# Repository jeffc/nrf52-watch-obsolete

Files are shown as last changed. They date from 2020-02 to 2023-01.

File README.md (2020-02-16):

# nrf52-watch

## Overview

This repo is, at present, a work-in-progress playground for designing and
building a smartwatch based on the nrf52840 microcontroller from Nordic.

## Parts

  * [RayTac MDBT50Q nRF52840 Module](https://www.raytac.com/product/ins.php?index_id=24)
    * Main brains. nRF52840 chipset chosen for BLE capability and low (&lt;1uA)
      sleep current.
    * This is the module used in the [Sparkfun Breakout](https://www.sparkfun.com/products/15025)
  * [Sharp LS018B7DH02 1.8" Memory LCD with FLExLight Frontlight](https://www.digikey.com/product-detail/en/flex-lighting/12616-06_T1/12616-06_T1-ND/9602610)
    * Always-on display.
    * Chosen for size and small power consumption.
    * The LS018B7DH02 isn't sold directly by Sharp, and no datasheet is
      currently available.
    * Unknowns are currently
      * Does the display require 3.3V or 5V power?
      * Does the display require 3.3V or 5V logic?
      * Does the display require a 1Hz or 60Hz square wave for biasing? 3.3V
        models tend to need 60Hz, but the 5V models need 1Hz
  * [M41T62Q6F RTC](https://www.digikey.com/product-detail/en/stmicroelectronics/M41T62Q6F/497-3907-1-ND/714738)
    * Realtime clock, for real timekeeping.
    * Chosen for small power consumption and footprint
    * This module can also provide the 1Hz or 64Hz square wave required by the
      memory LCD, which means fewer wakeups for the nRF52840
  * [MCP73831T Battery Charger IC](https://www.digikey.com/product-detail/en/microchip-technology/MCP73831T-2DCI-OT/MCP73831T-2DCI-OTCT-ND/1979804) 
    * Charges at 4.2V
  * USB-C port for power, charging, and data
    * I'm cheating here and using USB 2.0 Compatibility mode, so I don't get the
      benefits of USB-PD.

## Power

  * Project will be powered by a [500mAh LiPo](https://www.adafruit.com/product/1578),
    which has a nominal capacity of 500mAh at 3.7V.
    * Battery chosen has built-in overcurrent and undervoltage protection
      circuitry, meaning that I don't have to design any.
  * Projected lifetime is &gt;2mo, though it remains to be seen if this is
    possible

## Manufacture and Assembly

  * Prototypes of the case and mechanical components will be 3D printed.
  * Once I have a design that I like, I'll send the files to
    [Shapeways](http://shapeways.com) or [ExOne](http://exone.com) to be 3D
    Printed in steel.
  * Side buttons (required since the display is not a touch screen) will be on
    separate PCBs, connected via JST-SH cables to the main PCB. This allows me
    to use normal PCB buttons rather than right-angle ones, and gives some
    flexibility in mounting the main PCB.

## Software

  Since there isn't code written yet, this section is largely my notepad on
  ideas and framework setup.

  * To conserve power, everything will be interrupts-driven. 
  * PlatformIO doesn't have a builtin for the sparkfun dev board I'm using, so
    the packages/ directory and corresponding lines in platformio.ini are a
    workaround to keep the repository as portable as possible
  * A decent amount of build hackery was needed to make the native version build
    with the dummy adafruit_gfx library

## Credits / Inspiration

  * This project uses open-source code from the following projects. Licenses are
    included alongside code where applicable.
    * [Adafruit](https://github.com/adafruit/Adafruit-GFX-Library)
    * [vhervieux on github](https://github.com/croutor/Adafruit_GFX_dummy_display)
    * [jeraymond on github](https://github.com/jeraymond/pio-sparkfun_pro_nrf52840_mini-setup)
    * [UF2Conv from Microsoft](https://raw.githubusercontent.com/microsoft/uf2/master/utils/uf2conv.py)
  * This project took inspiration from these projects:
    * [Chronio](https://hackaday.io/project/12876-chronio)
    * [Samson March's Smartwatch](https://imgur.com/a/FSBwD3g)

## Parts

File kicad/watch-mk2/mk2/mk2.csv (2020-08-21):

Comment | Designator | Package | LCSC
Battery_Cell | BT1 | Connector_JST:JST_SH_BM02B-SRSS-TB_1x02-1MP_P1.00mm_Vertical
12pF | C1,C2 | Capacitor_SMD:C_0603_1608Metric_Pad1.05x0.95mm_HandSolder | C38523
0.47uF | C10 | Capacitor_SMD:C_0603_1608Metric_Pad1.05x0.95mm_HandSolder | C1623
10uF | C3,C6,C7,C8 | Capacitor_SMD:C_0603_1608Metric_Pad1.05x0.95mm_HandSolder | C19702
4.7uF | C4,C20 | Capacitor_SMD:C_0603_1608Metric_Pad1.05x0.95mm_HandSolder | C19666
11mF | C5 | Capacitor_SMD:C_1210_3225Metric_Pad1.42x2.65mm_HandSolder
560pF | C9 | Capacitor_SMD:C_0603_1608Metric_Pad1.05x0.95mm_HandSolder
D_Schottky_x2_KCom_AAK | D1 | Package_TO_SOT_SMD:TSOT-23
D_Schottky | D2 | Diode_SMD:D_0603_1608Metric_Pad1.05x0.95mm_HandSolder
MDBT50Q | IC1 | 113990582:113990582 | C155330
M41T62LC6F | IC2 | libs:LCC90P230X50X80-8N
Conn_01x10_Female | J1 | Connector_FFC-FPC:Hirose_FH12-10S-0.5SH_1x10-1MP_P0.50mm_Horizontal
USB_C_Receptacle_USB2.0 | J2 | Connector_USB:USB_C_Receptacle_Palconn_UTC16-G
Conn_01x02_Female | J3 | Connector_PinHeader_1.00mm:PinHeader_1x02_P1.00mm_Vertical
Conn_01x04_Female | J5 | libs:ffc-0.5mm-4
FUEL_BYP | JP1 | Resistor_SMD:R_0603_1608Metric
2.2uH | L1,L2 | Inductor_SMD:L_0603_1608Metric_Pad1.05x0.95mm_HandSolder
AXT610124 | P1 | libs:PANASONIC_AXT610124
Si1308EDL | Q3,Q4 | Package_TO_SOT_SMD:SOT-323_SC-70 | C469327
5.1k | R11,R12 | Resistor_SMD:R_0603_1608Metric_Pad1.05x0.95mm_HandSolder | C23186
1k | R14,R16 | Resistor_SMD:R_0603_1608Metric_Pad1.05x0.95mm_HandSolder | C21190
27 | R3,R4 | Resistor_SMD:R_0603_1608Metric_Pad1.05x0.95mm_HandSolder | C25190
100k | R5,R13,R15 | Resistor_SMD:R_0603_1608Metric_Pad1.05x0.95mm_HandSolder | C25803
10k | R6 | Resistor_SMD:R_0603_1608Metric_Pad1.05x0.95mm_HandSolder | C25804
2k | R9 | Resistor_SMD:R_0603_1608Metric_Pad1.05x0.95mm_HandSolder | C22975
B5 | SW1 | libs:E-Switch-TL3330AF130QG-MFG
B1 | SW2 | libs:E-Switch-TL3330AF130QG-MFG
B3 | SW4 | libs:E-Switch-TL3330AF130QG-MFG
SW_Push | SW_RESET1 | Button_Switch_SMD:SW_SPST_CK_KXT3
TestPoint | TP1,TP2,TP3,TP4 | TestPoint:TestPoint_Pad_D1.0mm
W25X20CLUXIG | U1 | libs:SON50P300X200X60-9N | C164121
LM3671MF-2.8_NOPB | U2 | Package_TO_SOT_SMD:SOT-23-5_HandSoldering
MCP73831-2-OT | U3 | Package_TO_SOT_SMD:SOT-23-5 | C14879
MAX17220ELT+ | U5 | max17220:Maxim_Integrated-L622-1C-0-E-IPC_A
MAX17262REWL+T | U6 | max17262:Maxim-W91G1-3-0-A-IPC_A
32.768kHz | Y1 | Crystal:Crystal_SMD_2012-2Pin_2.0x1.2mm_HandSoldering

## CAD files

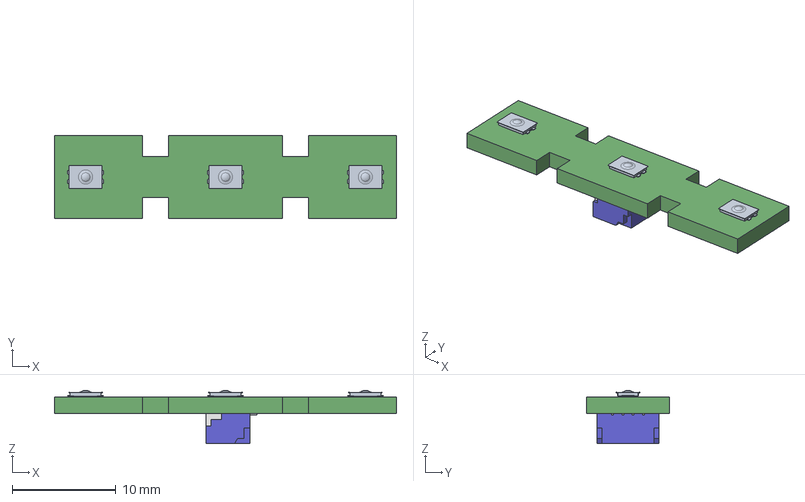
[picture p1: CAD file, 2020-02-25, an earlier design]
kicad/watch/buttonpanel/buttonpanel/buttonpanel.step
33.0 x 8.00 x 5.15 mm

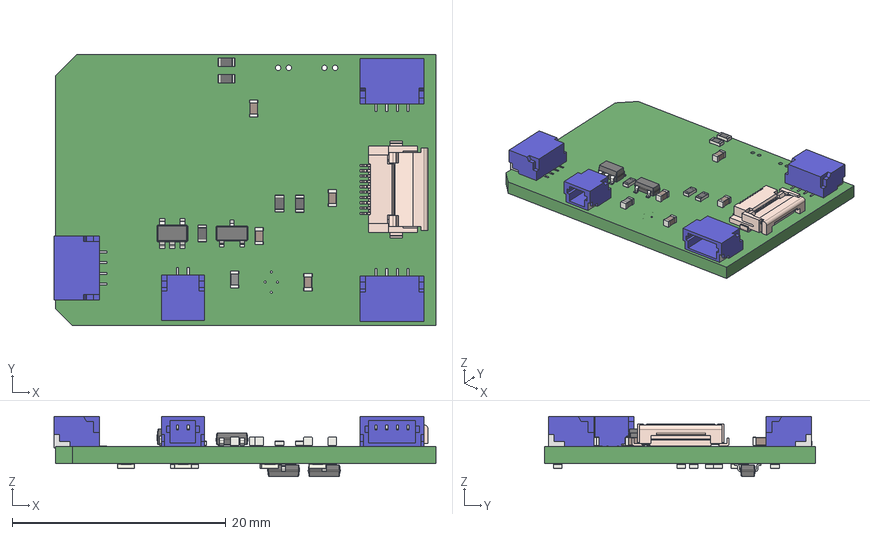
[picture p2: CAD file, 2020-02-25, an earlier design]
kicad/watch/watch.step
35.7 x 25.4 x 5.66 mm

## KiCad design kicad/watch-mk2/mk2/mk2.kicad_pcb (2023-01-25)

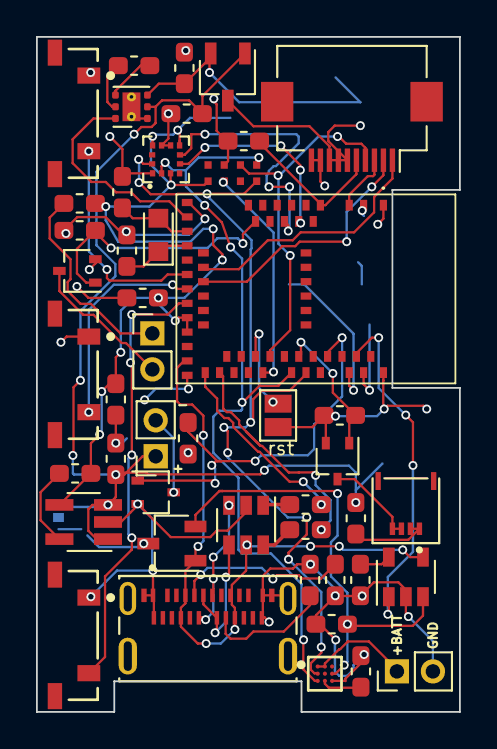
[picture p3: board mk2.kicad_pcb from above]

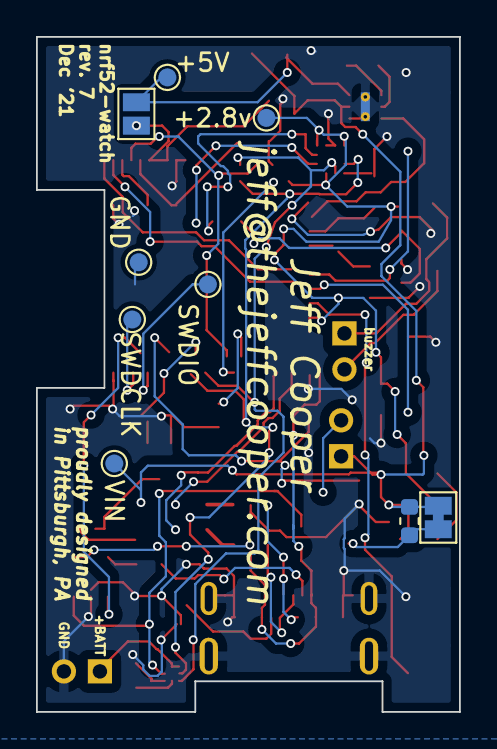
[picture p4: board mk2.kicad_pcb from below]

Board: 2 copper layers, 23.5 x 37.5 mm, 55 parts (9 on the bottom side), 50 nets.

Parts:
BT1: Battery_Cell; PinHeader_1x02_P2.00mm_Vertical
C1, C2: 12pF; C_0603_1608Metric_Pad1.05x0.95mm_HandSolder
C3, C7: 10uF; C_0603_1608Metric_Pad1.05x0.95mm_HandSolder
C4, C20: 4.7uF; C_0603_1608Metric_Pad1.05x0.95mm_HandSolder
C5, C6, C8: 2.2uF; C_0603_1608Metric_Pad1.05x0.95mm_HandSolder
C9: 560pF; C_0603_1608Metric_Pad1.05x0.95mm_HandSolder
C10: 0.47uF; C_0603_1608Metric_Pad1.05x0.95mm_HandSolder
D1, D2: D_Schottky_x2_KCom_AAK; TSOT-23
IC1: MDBT50Q; 113990582
IC2: M41T62LC6F; LCC90P230X50X80-8N
J1: Conn_01x10_Female; Hirose_FH12-10S-0.5SH_1x10-1MP_P0.50mm_Horizontal
J2: 2305018-2; TE_2305018-2
J3: Conn_01x02_Female; PinHeader_1x02_P2.00mm_Vertical
J4: 503480-0400; MOLEX_503480-0400
J6: Conn_01x02_Female; PinSocket_1x02_P2.00mm_Vertical
JP1, JP2: Jumper_NO_Small; SolderJumper-2_P1.3mm_Open_Pad1.0x1.5mm
JP3: Jumper_NC_Small; SolderJumper-2_P1.3mm_Bridged_Pad1.0x1.5mm
L1: 2.2uH; L_0603_1608Metric_Pad1.05x0.95mm_HandSolder
Q1, Q3, Q4: Si1308EDL; SOT-323_SC-70
R1: shunt; R_0603_1608Metric
R2, R13, R15: 100k; R_0603_1608Metric_Pad1.05x0.95mm_HandSolder
R3, R4: 27; R_0603_1608Metric_Pad1.05x0.95mm_HandSolder
R9: 2k; R_0603_1608Metric_Pad1.05x0.95mm_HandSolder
R11, R12: 5.1k; R_0603_1608Metric_Pad1.05x0.95mm_HandSolder
R14: 100; R_0603_1608Metric_Pad1.05x0.95mm_HandSolder
R16: 10; R_0603_1608Metric_Pad1.05x0.95mm_HandSolder
SW1: B5; E-Switch-TL3330AF130QG-MFG
SW2: B1; E-Switch-TL3330AF130QG-MFG
SW4: B3; E-Switch-TL3330AF130QG-MFG
TP1, TP2, TP3, TP4, TP5, TP6: TestPoint; TestPoint_Pad_D1.0mm
U1: TPS60151DRV; WSON-6-1EP_2x2mm_P0.65mm_EP1x1.6mm_ThermalVias
U2: LM3671MF-2.8_NOPB; SOT-23-5_HandSoldering
U3: MCP73831-2-OT; SOT-23-5
U4: BMA400; XDCR_BMA400
U5: TPD2S017; SOT-23-6
U6: MAX17262REWL+T; Maxim-W91G1-3-0-A-IPC_A
Y1: 32.768kHz; Crystal_SMD_2012-2Pin_2.0x1.2mm_HandSoldering

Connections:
5VREG_EN: IC1.16 (P0.27), U1.6 (ENA)
+5V: C8.1, D2.2 (A), JP1.2, TP6.1, U1.3 (VOUT)
+BATT: BT1.1 (+), U6.A1 (TH), U6.A2 (BATT)
/XL1: C1.2, IC1.17 (P0.00/XL1), Y1.2
/XL2: C2.2, IC1.18 (P0.01/XL2), Y1.1
ACCELINT1: IC1.7 (P1.14), U4.5 (INT1)
ACCELINT2: IC1.9 (P0.03), U4.6 (INT2)
BACKLIGHT: IC1.45 (P0.23), Q3.1 (G), R13.1
BATTPOW: C20.1, D1.2 (A), U3.3 (VBAT), U6.B3 (SYS)
BUTTON1: IC1.22 (P0.06), SW2.2
BUTTON3: IC1.26 (P1.09), SW4.2
BUTTON5: IC1.24 (P0.08), SW1.2
BUZZER: IC1.13 (P0.28), Q4.1 (G), R15.1
CHGNG: IC1.52 (P0.09/NFC1), U3.1 (STAT)
DISP_POWER: D2.3 (K), J1.6, J1.7, J1.8, JP1.1
FLASHLIGHT: IC1.49 (P0.25), Q1.1 (G), R2.1
GND: BT1.2 (-), C1.1, C2.1, C3.2, C4.2, C5.1, C7.2, C8.2, C9.2, C10.2, C20.2, IC1.1 (GND_1), IC1.2 (GND_2), IC1.15 (GND_3), IC1.33 (GND_4), IC1.55 (GND_5), IC2.3 (VSS), J1.9, J1.10, J2.A1 (GNDA), J2.A12 (GNDA__1), J2.B1 (GNDB), J2.B12 (GNDB__1), J2.G1 (GND), J2.G2 (GND__1), J2.S1 (SHIELD), J2.S2 (SHIELD__1), J2.S3 (SHIELD__2), J2.S4 (SHIELD__3), JP2.2, Q1.2 (S), Q3.2 (S), Q4.2 (S), R2.2, R9.2, R11.2, R12.1, R13.2, R15.2, SW1.1, SW2.1, SW4.1, TP1.1, U1.1 (GND), U1.7 (EP), U2.2 (GND), U3.2 (VSS), U4.1 (SDO), U4.8 (GNDIO), U4.9 (GND), U5.2 (GND), U6.C3 (GND)
LCD_CS: IC1.3 (P1.10), J1.3
LCD_DISP: C9.1, IC1.4 (P1.11), J1.5
unnamed: C6.1, U1.4 (CP+)
unnamed: C6.2, U1.5 (CP-)
unnamed: C10.1, U6.C2 (REG)
unnamed: D1.3 (K), JP3.2, R1.1
unnamed: IC1.34 (D-), R3.1
unnamed: IC1.35 (D+), R4.1
unnamed: J3.1, R16.2
unnamed: J3.2, Q4.3 (D)
unnamed: J4.1, J4.2, R14.2
unnamed: J4.3, J4.4, Q3.3 (D)
unnamed: J6.2, Q1.3 (D)
unnamed: L1.1, U2.5 (SW)
unnamed: R9.1, U3.5 (PROG)
unnamed: J2.B5 (CC2), R11.1
unnamed: J2.A5 (CC1), R12.2
RST: IC1.40 (P0.18/RESET), JP2.1
RTCIRQ: IC1.41 (P0.17), IC2.6 (~IRQ/OUT~)
SCL: IC1.46 (P0.22), IC2.8 (SCL), U4.12 (SCX), U6.B1 (SCL)
SDA: IC1.44 (P0.20), IC2.1 (SDA), U4.2 (SDX), U6.C1 (SDA)
SPI_CLK: IC1.21 (P0.05), J1.1
SPI_MOSI: IC1.23 (P0.07), J1.2
SQW: IC1.42 (P0.19), IC2.2 (SQW), J1.4
SWDCLK: IC1.53 (SWDCLK), TP2.1
SWDIO: IC1.51 (SWDIO), TP4.1
USB_DN: R3.2, U5.1 (CH1Out)
USB_DN_EXT: J2.A7 (DA_N), J2.B7 (DB_N), U5.3 (CH1In)
USB_DP: R4.2, U5.6 (CH2Out)
USB_DP_EXT: J2.A6 (DA_P), J2.B6 (DB_P), U5.4 (CH2Int)
VCC: C3.1, C7.1, IC1.28 (VDD), IC1.30 (VDDH), IC2.5 (VCC), L1.2, R16.1, TP3.1, U2.4 (FB), U4.3 (VDDIO), U4.7 (VDD), U4.10 (~CSB~)
VIN: C4.1, C5.2, D2.1 (A), J6.1, JP3.1, R1.2, R14.1, TP5.1, U1.2 (VIN), U2.1 (VIN), U2.3 (EN)
VUSB: D1.1 (A), IC1.32 (VBUS), J2.A4 (VBUS_A), J2.A9 (VBUS_A__1), J2.B4 (VBUS_B), J2.B9 (VBUS_B__1), U3.4 (VDD), U5.5 (VCC)

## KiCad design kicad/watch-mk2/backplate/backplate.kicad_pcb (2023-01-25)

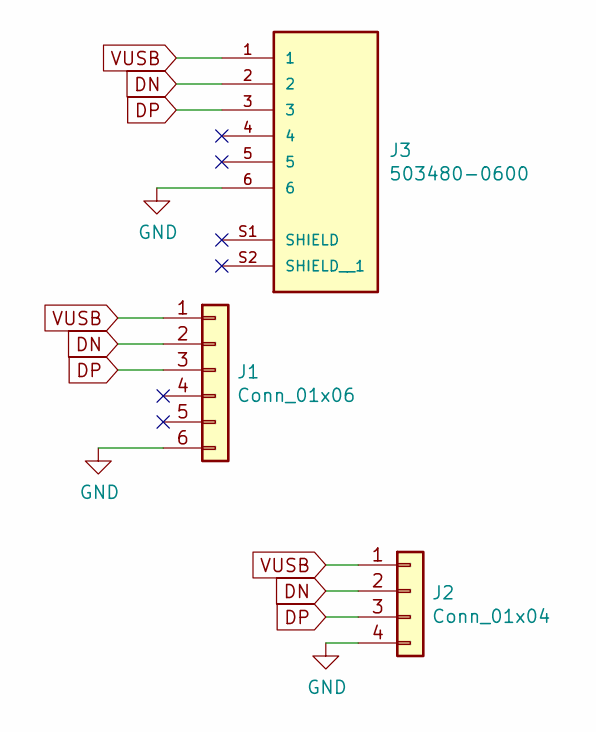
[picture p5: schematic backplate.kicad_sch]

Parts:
J1: Conn_01x06; ffc-strip
J2: Conn_01x04; PinHeader_1x04_P2.00mm_Vertical
J3: 503480-0600; MOLEX_503480-0600; PARTREV H

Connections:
DN: J1.2, J2.2, J3.2
DP: J1.3, J2.3, J3.3
GND: J1.6, J2.4, J3.6
VUSB: J1.1, J2.1, J3.1

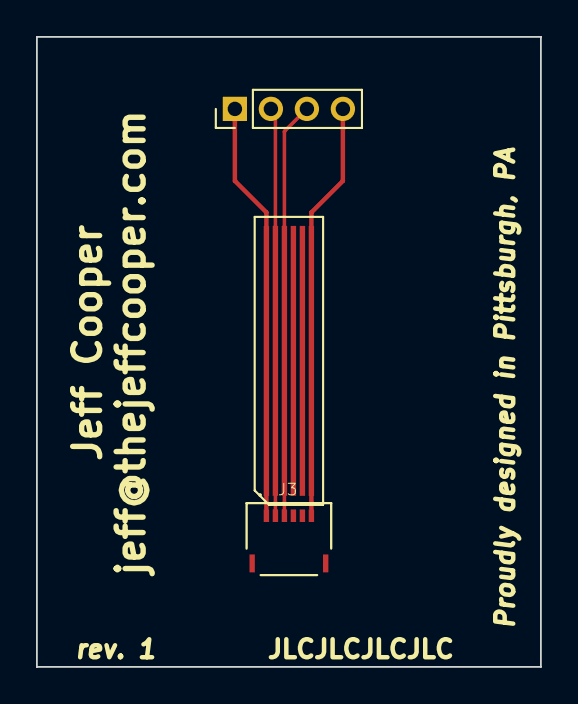
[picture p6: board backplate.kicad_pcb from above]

Board: 2 copper layers, 28.0 x 35.0 mm, 3 parts (0 on the bottom side), 4 nets.

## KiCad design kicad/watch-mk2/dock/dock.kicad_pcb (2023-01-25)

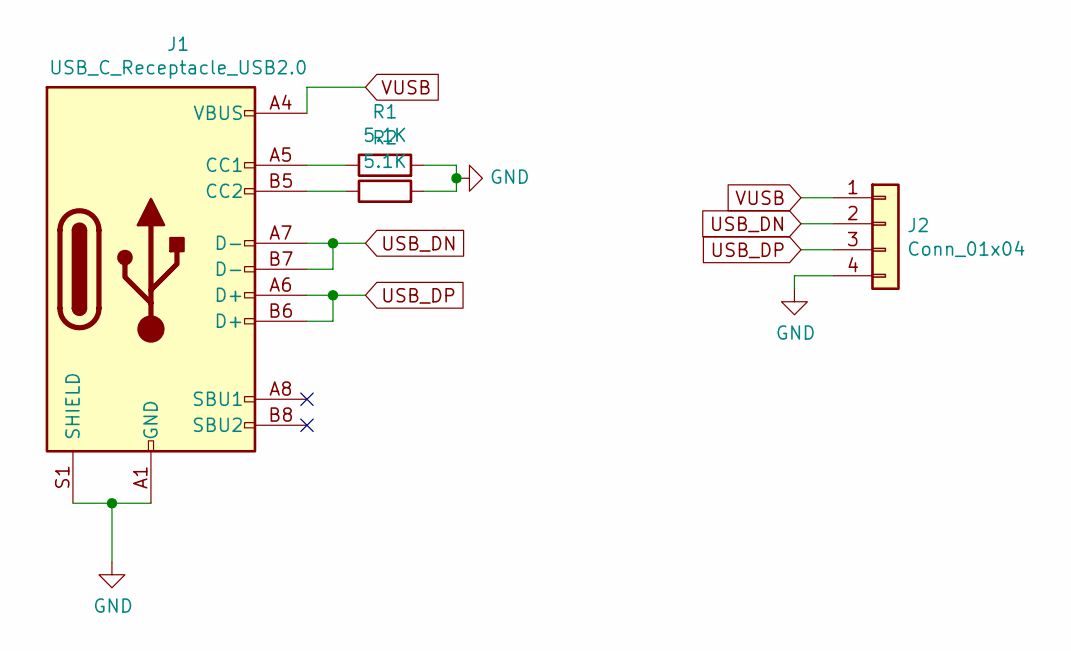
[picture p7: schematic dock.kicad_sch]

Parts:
J1: USB_C_Receptacle_USB2.0; USB_C_Receptacle_Palconn_UTC16-G
J2: Conn_01x04; pins
R1, R2: 5.1K; R_0603_1608Metric

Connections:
GND: J1.A1 (GND), J1.A12 (GND), J1.B1 (GND), J1.B12 (GND), J1.S1 (SHIELD), J2.4, R1.2, R2.2
unnamed: J1.A5 (CC1), R1.1
unnamed: J1.B5 (CC2), R2.1
USB_DN: J1.A7 (D-), J1.B7 (D-), J2.2
USB_DP: J1.A6 (D+), J1.B6 (D+), J2.3
VUSB: J1.A4 (VBUS), J1.A9 (VBUS), J1.B4 (VBUS), J1.B9 (VBUS), J2.1

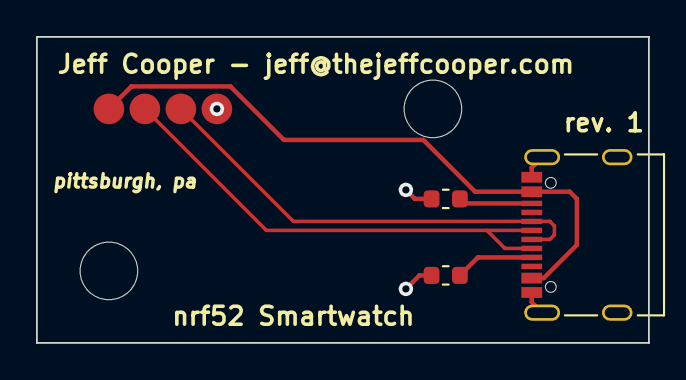
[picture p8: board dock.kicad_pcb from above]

Board: 2 copper layers, 34.0 x 17.0 mm, 4 parts (0 on the bottom side), 6 nets.

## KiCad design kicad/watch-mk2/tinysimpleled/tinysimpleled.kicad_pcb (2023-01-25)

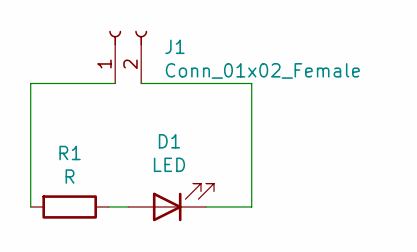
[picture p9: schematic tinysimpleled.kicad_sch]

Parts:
D1: LED; XM-L2
J1: Conn_01x02_Female; PinHeader_1x02_P1.00mm_Vertical
R1: R; R_2512_6332Metric

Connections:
unnamed: D1.1 (K), J1.2
unnamed: D1.2 (A), R1.1
unnamed: J1.1, R1.2

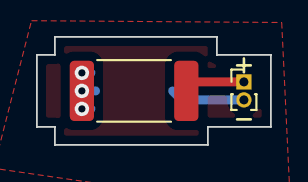
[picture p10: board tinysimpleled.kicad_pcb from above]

Board: 2 copper layers, 13.0 x 6.0 mm, 3 parts (1 on the bottom side), 3 nets.

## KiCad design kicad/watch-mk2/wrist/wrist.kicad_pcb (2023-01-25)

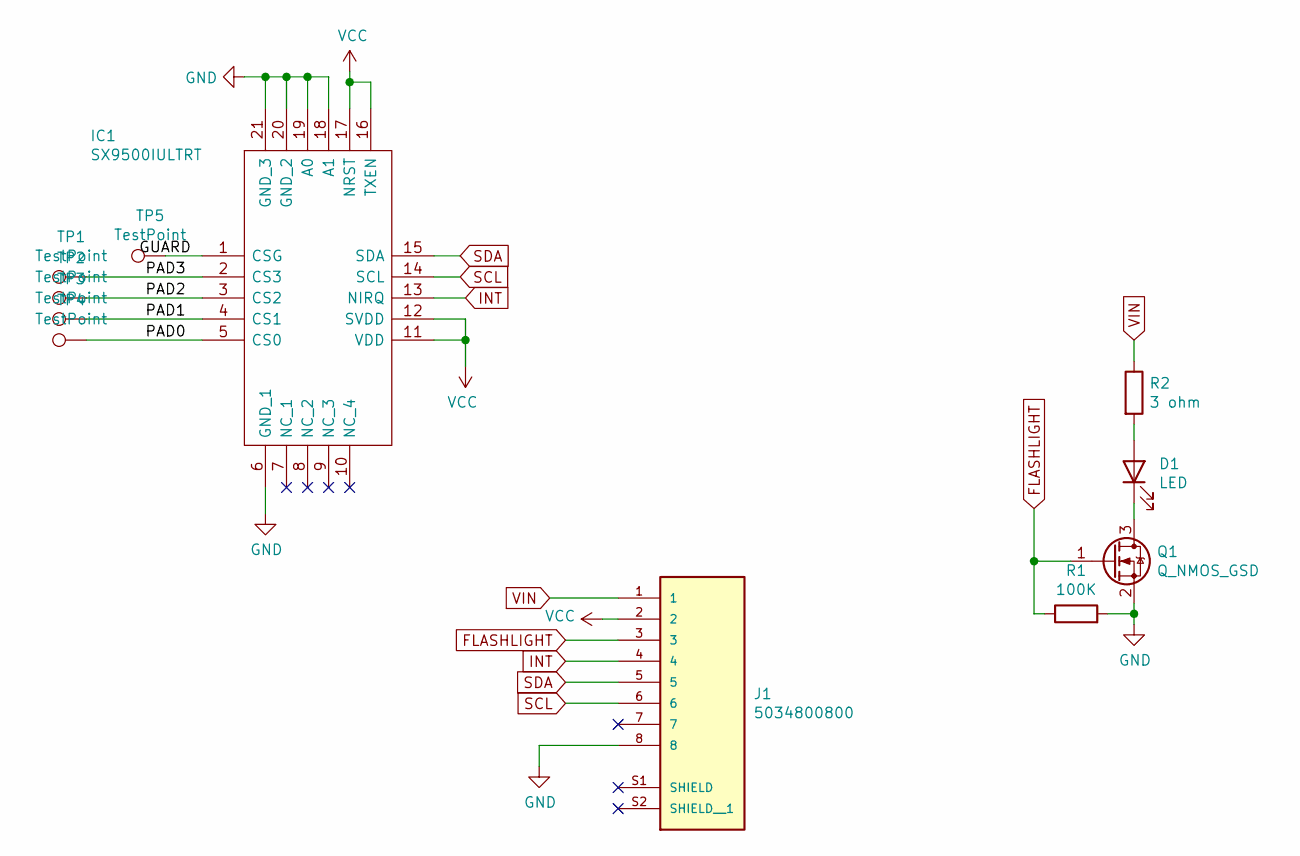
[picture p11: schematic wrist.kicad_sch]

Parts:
D1: LED; XM-L2
IC1: SX9500IULTRT; QFN40P300X300X60-21N; Manufacturer_Part_Number SX9500IULTRT; Mouser Part Number 947-SX9500IULTRT
J1: 5034800800; MOLEX_5034800800; PARTREV H
Q1: Q_NMOS_GSD; SOT-323_SC-70
R1: 100K; R_0603_1608Metric
R2: 3 ohm; R_2512_6332Metric
TP1, TP2, TP3, TP4, TP5: TestPoint; TestPoint_Pad_D4.0mm

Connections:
/GUARD: IC1.1 (CSG), TP5.1
/PAD0: IC1.5 (CS0), TP4.1
/PAD1: IC1.4 (CS1), TP3.1
/PAD2: IC1.3 (CS2), TP2.1
/PAD3: IC1.2 (CS3), TP1.1
FLASHLIGHT: J1.3, Q1.1 (G), R1.1
GND: IC1.6 (GND_1), IC1.18 (A1), IC1.19 (A0), IC1.20 (GND_2), IC1.21 (GND_3), J1.8, Q1.2 (S), R1.2
INT: IC1.13 (NIRQ), J1.4
unnamed: D1.1 (K), Q1.3 (D)
unnamed: D1.2 (A), R2.2
SCL: IC1.14 (SCL), J1.6
SDA: IC1.15 (SDA), J1.5
VCC: IC1.11 (VDD), IC1.12 (SVDD), IC1.16 (TXEN), IC1.17 (NRST), J1.2
VIN: J1.1, R2.1

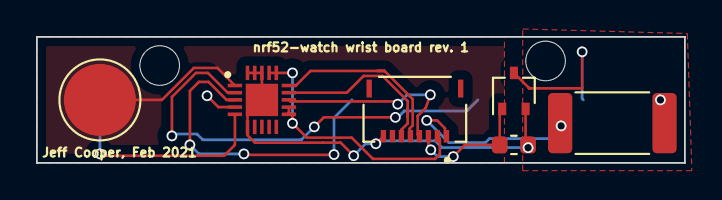
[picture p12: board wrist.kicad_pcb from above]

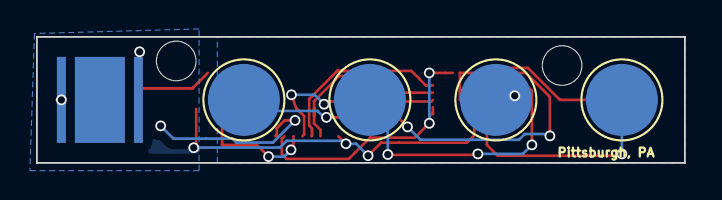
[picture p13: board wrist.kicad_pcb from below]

Board: 2 copper layers, 36.0 x 7.0 mm, 11 parts (5 on the bottom side), 14 nets.

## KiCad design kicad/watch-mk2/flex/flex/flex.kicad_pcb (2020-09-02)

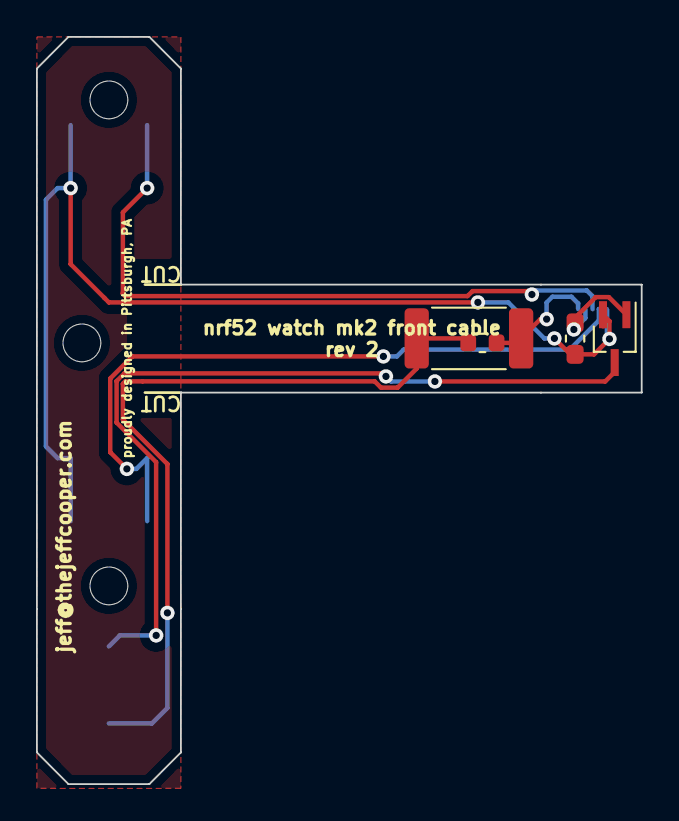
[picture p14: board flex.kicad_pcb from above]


Board: 2 copper layers, 33.6 x 41.5 mm, 8 parts (4 on the bottom side), 7 nets.

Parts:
D1: LED; XM-L2
P1: AXT510124; PANASONIC_AXT510124
Q1: Si1308EDL; SOT-323_SC-70_Handsoldering
R1: 100k; R_0603_1608Metric_Pad1.05x0.95mm_HandSolder
R2: 3; R_2512_6332Metric
R3: 3; R_0603_1608Metric
SW1, SW2: MCSLPT4644B4PHTR; MCSLPT4644PH

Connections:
BUTTON2: P1.5, SW1.1
BUTTON4: P1.7, SW2.1
FLASHLIGHT: P1.3, Q1.1 (G), R1.1
GND: P1.9, Q1.2 (S), R1.2, SW1.2, SW2.2
unnamed: D1.1 (K), Q1.3 (D)
unnamed: D1.2 (A), R2.2, R3.2
VIN: P1.1, R2.1, R3.1

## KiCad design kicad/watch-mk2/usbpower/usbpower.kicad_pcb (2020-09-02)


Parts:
P1, P2: USB_C_Plug_USB2.0; USB_C_Receptacle_Palconn_UTC16-G
TP1, TP2: TestPoint; TestPoint_Pad_D4.0mm

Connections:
unnamed: P1.A1 (GND), P1.A12 (GND), P1.B1 (GND), P1.B12 (GND), P2.A1 (GND), P2.A12 (GND), P2.B1 (GND), P2.B12 (GND)
unnamed: P1.A4 (VBUS), P1.A9 (VBUS), P1.B4 (VBUS), P1.B9 (VBUS), TP1.1
unnamed: P1.A5 (CC1), P2.A5 (CC1)
unnamed: P1.A6 (D+), P2.A6 (D+)
unnamed: P1.A7 (D-), P2.A7 (D-)
unnamed: P1.A8 (SBU1), P2.A8 (SBU1)
unnamed: P1.B5 (CC2), P2.B5 (CC2)
unnamed: P1.B6 (D+), P2.B6 (D+)
unnamed: P1.B7 (D-), P2.B7 (D-)
unnamed: P1.B8 (SBU2), P2.B8 (SBU2)
unnamed: P1.S1 (SHIELD), P2.S1 (SHIELD)
unnamed: P2.A4 (VBUS), P2.A9 (VBUS), P2.B4 (VBUS), P2.B9 (VBUS), TP2.1


Board: 2 copper layers, 22.0 x 16.0 mm, 4 parts (0 on the bottom side), 12 nets.

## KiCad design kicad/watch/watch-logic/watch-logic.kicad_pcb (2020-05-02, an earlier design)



Board: 2 copper layers, 25.4 x 25.4 mm, 41 parts (8 on the bottom side), 39 nets.

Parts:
C1: 11mF; C_1210_3225Metric_Pad1.42x2.65mm_HandSolder
C2: 1uF; C_0603_1608Metric_Pad1.05x0.95mm_HandSolder
D1: D_Schottky; D_SOT-23_ANK
IC1: 113990582
IC2: M41T62LC6F; LCC90P230X50X80-8N
J1, J2: Conn_01x04_Female; JST_SH_SM04B-SRSS-TB_1x04-1MP_P1.00mm_Horizontal
J3: Buzzer; PinHeader_1x02_P1.00mm_Vertical
J4: Memory LCD; Hirose_FH12-10S-0.5SH_1x10-1MP_P0.50mm_Horizontal
J5: Conn_01x04_Female; MOLEX_503480-0400
JP1, JP2: Jumper_NO_Small; SolderJumper-2_P1.3mm_Open_RoundedPad1.0x1.5mm
P1: AXT610124; PANASONIC_AXT610124
Q1, Q2: DMN6140L; SOT-23
R1, R2: 27; R_0603_1608Metric_Pad1.05x0.95mm_HandSolder
R3, R4: 10k; R_0603_1608Metric_Pad1.05x0.95mm_HandSolder
R5, R6: 4k7; R_0603_1608Metric_Pad1.05x0.95mm_HandSolder
R7, R8, R9, R10: R; R_0603_1608Metric_Pad1.05x0.95mm_HandSolder
SW_BOOT1: SW_Push; SW_SPST_CK_KXT3
SW_RESET1: SW_Push; SW_SPST_CK_KXT3
TP1, TP2, TP3, TP4, TP5, TP6, TP7, TP8, TP9, TP10, TP11, TP12: TestPoint; TestPoint_Pad_D1.0mm
U1: W25X20CLUXIG; 8-USON
Y1: Crystal; Crystal_SMD_2012-2Pin_2.0x1.2mm_HandSoldering

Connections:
+3V3: D1.2, IC1.28, J3.1, J5.1, J5.2, JP1.2, JP2.2, P1.2, R3.1, R4.1, R5.1, R6.1, TP1.1, U1.3, U1.7, U1.8
+5V: C2.1, J4.5, J4.6, J4.7, P1.10
BOOTLOAD: IC1.3, R4.2, SW_BOOT1.1
BTN1: IC1.12, J1.4
BTN2: IC1.11, J1.2, JP1.1
BTN3: IC1.9, J1.3
BTN4: IC1.29, J2.4
BTN5: IC1.27, J2.3
BTN6: IC1.26, J2.2, JP2.1
BUZZER: IC1.56, Q1.1, R7.2
EXTMODE: IC1.8, J4.8
FLASH_CLK: IC1.48, TP6.1, U1.6
FLASH_CS: IC1.49, TP7.1, U1.1
FLASH_DI: IC1.47, TP5.1, U1.5
FLASH_DO: IC1.50, TP8.1, U1.2
FRONTLIGHT: IC1.42, Q2.1, R9.2
GND: C1.2, C2.2, IC1.1, IC1.2, IC1.15, IC1.33, IC1.55, IC2.3, J1.1, J2.1, J4.9, J4.10, P1.1, Q1.2, Q2.2, R7.1, R9.1, SW_BOOT1.2, SW_RESET1.2, TP2.1, U1.4
LCD_CLK: IC1.4, J4.1
LCD_CS: IC1.6, J4.3
LCD_MOSI: IC1.5, J4.2
unnamed: C1.1, D1.1, IC2.5
unnamed: IC1.17, Y1.1
unnamed: IC1.18, Y1.2
unnamed: IC1.34, R1.2
unnamed: IC1.35, R2.2
unnamed: J3.2, R8.1
unnamed: J5.3, J5.4, R10.1
unnamed: Q1.3, R8.2
unnamed: Q2.3, R10.2
RST: IC1.40, R3.2, SW_RESET1.1
RTC_IRQ: IC1.21, IC2.6, TP12.1
SCL: IC1.22, IC2.8, P1.6, R6.2, TP9.1
SDA: IC1.23, IC2.1, P1.4, R5.2, TP10.1
SQW: IC1.24, IC2.2, J4.4, TP11.1
SWDCLK: IC1.53, TP3.1
SWDIO: IC1.51, TP4.1
USB_DN: P1.5, R1.1
USB_DP: P1.3, R2.1
VBUS: IC1.32, P1.9

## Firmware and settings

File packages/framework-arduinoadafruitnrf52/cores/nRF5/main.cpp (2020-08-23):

/*
  Copyright (c) 2015 Arduino LLC.  All right reserved.
  This library is free software; you can redistribute it and/or
  modify it under the terms of the GNU Lesser General Public
  License as published by the Free Software Foundation; either
  version 2.1 of the License, or (at your option) any later version.
  This library is distributed in the hope that it will be useful,
  but WITHOUT ANY WARRANTY; without even the implied warranty of
  MERCHANTABILITY or FITNESS FOR A PARTICULAR PURPOSE.
  See the GNU Lesser General Public License for more details.
  You should have received a copy of the GNU Lesser General Public
  License along with this library; if not, write to the Free Software
  Foundation, Inc., 51 Franklin St, Fifth Floor, Boston, MA  02110-1301  USA
*/

#define ARDUINO_MAIN
#include "Arduino.h"

// DEBUG Level 1
#if CFG_DEBUG
// weak function to avoid compilation error with
// non-Bluefruit library sketch such as ADC read test
void Bluefruit_printInfo() __attribute__((weak));
void Bluefruit_printInfo() {}
#endif

// DEBUG Level 3
#if CFG_DEBUG >= 3
#include "SEGGER_SYSVIEW.h"
#endif

static TaskHandle_t  _loopHandle;


// Weak empty variant initialization function.
// May be redefined by variant files.
void initVariant() __attribute__((weak));
void initVariant() { }

#define LOOP_STACK_SZ       (256*4)
#define CALLBACK_STACK_SZ   (256*3)

static void loop_task(void* arg)
{
  (void) arg;

#if CFG_DEBUG
  // If Serial is not begin(), call it to avoid hard fault
  Serial.begin(115200);

  // Wait for Serial connection in debug mode
  while ( !Serial ) yield();

  dbgPrintVersion();
#endif

  setup();

#if CFG_DEBUG
  Bluefruit_printInfo();
#endif

  while (1)
  {
    loop();
    yield(); // yield to run other task

    // Serial events
    if (serialEvent && serialEventRun) serialEventRun();
  }
}

// \brief Main entry point of Arduino application
int main( void )
{
  init();
  initVariant();

#ifdef USE_TINYUSB
  Adafruit_TinyUSB_Core_init();
#endif

#if CFG_DEBUG >= 3
  SEGGER_SYSVIEW_Conf();
#endif

  // Create a task for loop()
  xTaskCreate( loop_task, "loop", LOOP_STACK_SZ, NULL, TASK_PRIO_LOW, &_loopHandle);

  // Initialize callback task
  ada_callback_init(CALLBACK_STACK_SZ);

  // Start FreeRTOS scheduler.
  vTaskStartScheduler();

  NVIC_SystemReset();

  return 0;
}

void suspendLoop(void)
{
  vTaskSuspend(_loopHandle);
}

extern "C"
{

// nanolib printf() retarget
int _write (int fd, const void *buf, size_t count)
{
  (void) fd;

  if ( Serial )
  {
    return Serial.write( (const uint8_t *) buf, count);
  }
  return 0;
}

}

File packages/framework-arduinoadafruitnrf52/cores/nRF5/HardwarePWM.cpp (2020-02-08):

/**************************************************************************/
/*!
    @file     HardwarePWM.cpp
    @author   hathach (tinyusb.org)

    @section LICENSE

    Software License Agreement (BSD License)

    Copyright (c) 2018, Adafruit Industries (adafruit.com)
    All rights reserved.

    Redistribution and use in source and binary forms, with or without
    modification, are permitted provided that the following conditions are met:
    1. Redistributions of source code must retain the above copyright
    notice, this list of conditions and the following disclaimer.
    2. Redistributions in binary form must reproduce the above copyright
    notice, this list of conditions and the following disclaimer in the
    documentation and/or other materials provided with the distribution.
    3. Neither the name of the copyright holders nor the
    names of its contributors may be used to endorse or promote products
    derived from this software without specific prior written permission.

    THIS SOFTWARE IS PROVIDED BY THE COPYRIGHT HOLDERS ''AS IS'' AND ANY
    EXPRESS OR IMPLIED WARRANTIES, INCLUDING, BUT NOT LIMITED TO, THE IMPLIED
    WARRANTIES OF MERCHANTABILITY AND FITNESS FOR A PARTICULAR PURPOSE ARE
    DISCLAIMED. IN NO EVENT SHALL THE COPYRIGHT HOLDER BE LIABLE FOR ANY
    DIRECT, INDIRECT, INCIDENTAL, SPECIAL, EXEMPLARY, OR CONSEQUENTIAL DAMAGES
    (INCLUDING, BUT NOT LIMITED TO, PROCUREMENT OF SUBSTITUTE GOODS OR SERVICES;
    LOSS OF USE, DATA, OR PROFITS; OR BUSINESS INTERRUPTION) HOWEVER CAUSED AND
    ON ANY THEORY OF LIABILITY, WHETHER IN CONTRACT, STRICT LIABILITY, OR TORT
    (INCLUDING NEGLIGENCE OR OTHERWISE) ARISING IN ANY WAY OUT OF THE USE OF THIS
    SOFTWARE, EVEN IF ADVISED OF THE POSSIBILITY OF SUCH DAMAGE.
*/
/**************************************************************************/

#include "Arduino.h"
#include "HardwarePWM.h"

HardwarePWM HwPWM0(NRF_PWM0);
HardwarePWM HwPWM1(NRF_PWM1);
HardwarePWM HwPWM2(NRF_PWM2);

#ifdef NRF_PWM3
HardwarePWM HwPWM3(NRF_PWM3);
#endif

HardwarePWM* HwPWMx[] =
{
  &HwPWM0, &HwPWM1, &HwPWM2
#ifdef NRF_PWM3
  ,&HwPWM3
#endif
};

HardwarePWM::HardwarePWM(NRF_PWM_Type* pwm)
{
  _pwm = pwm;
  arrclr(_seq0);

  _max_value = 255;
  _clock_div = PWM_PRESCALER_PRESCALER_DIV_1; // 16 Mhz

  // FIXME workaround to fix bootloader 0.2.6 does not clean up PSEL[1] of PWM0
  _pwm->PSEL.OUT[1] = 0xFFFFFFFFUL;
}

void HardwarePWM::setResolution(uint8_t bitnum)
{
  setMaxValue( bit(min8(bitnum, 15)) -1 );
}

void HardwarePWM::setMaxValue(uint16_t value)
{
  _max_value = value;
  _pwm->COUNTERTOP = value;
}

void HardwarePWM::setClockDiv(uint8_t div)
{
  _clock_div = min8(div, PWM_PRESCALER_PRESCALER_DIV_128);
  _pwm->PRESCALER = _clock_div;
}

/**
 * Add pin to this group.
 * @param pin Pin to add
 * @return true if add succeeded, or pin is already added
 */
bool HardwarePWM::addPin(uint8_t pin)
{
  // succeed if pin is already configured
  if ( pin2channel(pin) >= 0 ) return true;

  int ch = -1;

  // find free slot which is not connected
  for(int i=0; i<MAX_CHANNELS; i++)
  {
    if ( _pwm->PSEL.OUT[i] & PWM_PSEL_OUT_CONNECT_Msk )
    {
      ch = i;
      break;
    }
  }
  VERIFY ( ch >= 0 );

  pinMode(pin, OUTPUT);
  digitalWrite(pin, LOW);

  // Must disable before changing PSEL
  if ( enabled() )
  {
    _pwm->ENABLE = 0;
    _pwm->PSEL.OUT[ch] = g_ADigitalPinMap[pin];
    _pwm->ENABLE = 1;
    _start();
  }else
  {
    _pwm->PSEL.OUT[ch] = g_ADigitalPinMap[pin];
  }

  return true;
}

bool HardwarePWM::removePin(uint8_t pin)
{
  int ch = pin2channel(pin);
  VERIFY( ch >= 0 );

  bool const en = enabled();

  // Must disable before changing PSEL
  if ( en ) _pwm->ENABLE = 0;

  _pwm->PSEL.OUT[ch] = 0xFFFFFFFFUL;
  _seq0[ch] = 0;

  if ( en ) _pwm->ENABLE = 1;

  return true;
}

bool HardwarePWM::enabled (void)
{
  return _pwm->ENABLE;
}

void HardwarePWM::begin(void)
{
  // Initialize Registers
  _pwm->MODE            = PWM_MODE_UPDOWN_Up;
  _pwm->COUNTERTOP      = _max_value; // default is 255 (8 bit), can be configured before begin()
  _pwm->PRESCALER       = _clock_div;
  _pwm->DECODER         = PWM_DECODER_LOAD_Individual;
  _pwm->LOOP            = 0;

  _pwm->SEQ[0].PTR      = (uint32_t) _seq0;
  _pwm->SEQ[0].CNT      = MAX_CHANNELS; // default mode is Individual --> count must be 4
  _pwm->SEQ[0].REFRESH  = 0;
  _pwm->SEQ[0].ENDDELAY = 0;

  _pwm->SEQ[1].PTR      = 0;
  _pwm->SEQ[1].CNT      = 0;
  _pwm->SEQ[1].REFRESH  = 0;
  _pwm->SEQ[1].ENDDELAY = 0;

  _pwm->ENABLE = 1;
}

void HardwarePWM::_start(void)
{
  // update sequence count (depending on mode)
  //  _pwm->SEQ[0].CNT = MAX_CHANNELS;

  // start sequence
  _pwm->TASKS_SEQSTART[0] = 1;
}

void HardwarePWM::stop(void)
{
  _pwm->ENABLE = 0;
}
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

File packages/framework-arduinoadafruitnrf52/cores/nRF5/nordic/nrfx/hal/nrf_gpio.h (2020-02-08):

/*
 * Copyright (c) 2015 - 2019, Nordic Semiconductor ASA
 * All rights reserved.
 *
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
 * 2. Redistributions in binary form must reproduce the above copyright
 *    notice, this list of conditions and the following disclaimer in the
 *    documentation and/or other materials provided with the distribution.
 *
 * 3. Neither the name of the copyright holder nor the names of its
 *    contributors may be used to endorse or promote products derived from this
 *    software without specific prior written permission.
 *
 * THIS SOFTWARE IS PROVIDED BY THE COPYRIGHT HOLDERS AND CONTRIBUTORS "AS IS"
 * AND ANY EXPRESS OR IMPLIED WARRANTIES, INCLUDING, BUT NOT LIMITED TO, THE
 * IMPLIED WARRANTIES OF MERCHANTABILITY AND FITNESS FOR A PARTICULAR PURPOSE
 * ARE DISCLAIMED. IN NO EVENT SHALL THE COPYRIGHT HOLDER OR CONTRIBUTORS BE
 * LIABLE FOR ANY DIRECT, INDIRECT, INCIDENTAL, SPECIAL, EXEMPLARY, OR
 * CONSEQUENTIAL DAMAGES (INCLUDING, BUT NOT LIMITED TO, PROCUREMENT OF
 * SUBSTITUTE GOODS OR SERVICES; LOSS OF USE, DATA, OR PROFITS; OR BUSINESS
 * INTERRUPTION) HOWEVER CAUSED AND ON ANY THEORY OF LIABILITY, WHETHER IN
 * CONTRACT, STRICT LIABILITY, OR TORT (INCLUDING NEGLIGENCE OR OTHERWISE)
 * ARISING IN ANY WAY OUT OF THE USE OF THIS SOFTWARE, EVEN IF ADVISED OF THE
 * POSSIBILITY OF SUCH DAMAGE.
 */

#ifndef NRF_GPIO_H__
#define NRF_GPIO_H__

#include <nrfx.h>

#ifdef __cplusplus
extern "C" {
#endif

#ifndef NRF_P0
#define NRF_P0 NRF_GPIO
#endif

#if (GPIO_COUNT == 1)
#define NUMBER_OF_PINS (P0_PIN_NUM)
#define GPIO_REG_LIST  {NRF_P0}
#elif (GPIO_COUNT == 2)
#define NUMBER_OF_PINS (P0_PIN_NUM + P1_PIN_NUM)
#define GPIO_REG_LIST  {NRF_P0, NRF_P1}
#else
#error "Not supported."
#endif

/**
 * @defgroup nrf_gpio_hal GPIO HAL
 * @{
 * @ingroup nrf_gpio
 * @brief   Hardware access layer for managing the GPIO peripheral.
 */

/** @brief Macro for mapping port and pin numbers to values understandable for nrf_gpio functions. */
#define NRF_GPIO_PIN_MAP(port, pin) (((port) << 5) | ((pin) & 0x1F))


/** @brief Pin direction definitions. */
typedef enum
{
    NRF_GPIO_PIN_DIR_INPUT  = GPIO_PIN_CNF_DIR_Input, ///< Input.
    NRF_GPIO_PIN_DIR_OUTPUT = GPIO_PIN_CNF_DIR_Output ///< Output.
} nrf_gpio_pin_dir_t;

/** @brief Connection of input buffer. */
typedef enum
{
    NRF_GPIO_PIN_INPUT_CONNECT    = GPIO_PIN_CNF_INPUT_Connect,   ///< Connect input buffer.
    NRF_GPIO_PIN_INPUT_DISCONNECT = GPIO_PIN_CNF_INPUT_Disconnect ///< Disconnect input buffer.
} nrf_gpio_pin_input_t;

/**
 * @brief Enumerator used for selecting the pin to be pulled down or up at the time of pin
 * configuration.
 */
typedef enum
{
    NRF_GPIO_PIN_NOPULL   = GPIO_PIN_CNF_PULL_Disabled, ///<  Pin pull-up resistor disabled.
    NRF_GPIO_PIN_PULLDOWN = GPIO_PIN_CNF_PULL_Pulldown, ///<  Pin pull-down resistor enabled.
    NRF_GPIO_PIN_PULLUP   = GPIO_PIN_CNF_PULL_Pullup,   ///<  Pin pull-up resistor enabled.
} nrf_gpio_pin_pull_t;

/** @brief Enumerator used for selecting output drive mode. */
typedef enum
{
    NRF_GPIO_PIN_S0S1 = GPIO_PIN_CNF_DRIVE_S0S1, ///< !< Standard '0', standard '1'.
    NRF_GPIO_PIN_H0S1 = GPIO_PIN_CNF_DRIVE_H0S1, ///< !< High-drive '0', standard '1'.
    NRF_GPIO_PIN_S0H1 = GPIO_PIN_CNF_DRIVE_S0H1, ///< !< Standard '0', high-drive '1'.
    NRF_GPIO_PIN_H0H1 = GPIO_PIN_CNF_DRIVE_H0H1, ///< !< High drive '0', high-drive '1'.
    NRF_GPIO_PIN_D0S1 = GPIO_PIN_CNF_DRIVE_D0S1, ///< !< Disconnect '0' standard '1'.
    NRF_GPIO_PIN_D0H1 = GPIO_PIN_CNF_DRIVE_D0H1, ///< !< Disconnect '0', high-drive '1'.
    NRF_GPIO_PIN_S0D1 = GPIO_PIN_CNF_DRIVE_S0D1, ///< !< Standard '0', disconnect '1'.
    NRF_GPIO_PIN_H0D1 = GPIO_PIN_CNF_DRIVE_H0D1, ///< !< High-drive '0', disconnect '1'.
} nrf_gpio_pin_drive_t;

/** @brief Enumerator used for selecting the pin to sense high or low level on the pin input. */
typedef enum
{
    NRF_GPIO_PIN_NOSENSE    = GPIO_PIN_CNF_SENSE_Disabled, ///<  Pin sense level disabled.
    NRF_GPIO_PIN_SENSE_LOW  = GPIO_PIN_CNF_SENSE_Low,      ///<  Pin sense low level.
    NRF_GPIO_PIN_SENSE_HIGH = GPIO_PIN_CNF_SENSE_High,     ///<  Pin sense high level.
} nrf_gpio_pin_sense_t;


/**
 * @brief Function for configuring the GPIO pin range as output pins with normal drive strength.
 *        This function can be used to configure pin range as simple output with gate driving GPIO_PIN_CNF_DRIVE_S0S1 (normal cases).
 *
 * @note For configuring only one pin as output, use @ref nrf_gpio_cfg_output.
 *       Sense capability on the pin is disabled and input is disconnected from the buffer as the pins are configured as output.
 *
 * @param pin_range_start  Specifies the start number (inclusive) in the range of pin numbers to be configured (allowed values 0-30).
 * @param pin_range_end    Specifies the end number (inclusive) in the range of pin numbers to be configured (allowed values 0-30).
 */
__STATIC_INLINE void nrf_gpio_range_cfg_output(uint32_t pin_range_start, uint32_t pin_range_end);
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

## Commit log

2020-02-13 add first round of pcb files
    [watch.kicad_pcb, watch.sch]
2020-02-14 Second rev of schematic. Not yet routed.
    [watch.kicad_pcb, watch.sch]
2020-02-15 routed board rev2
    [_saved_watch.sch, watch.kicad_pcb, watch.sch]
2020-02-15 added voltage divider for battery reading
    [_saved_watch.sch, watch.kicad_pcb, watch.sch]
2020-02-16 Add qwiic jumpers for accessory ports
    [watch.kicad_pcb, watch.sch]
2020-02-17 add button panel, finish silk for main pcb
    [_saved_watch.sch, buttonpanel.kicad_pcb, buttonpanel.sch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]
2020-02-18 checkpoint before redoing schematic
    [_saved_watch.sch, watch.sch]
2020-02-18 add 3d files for most connectors, start on usbc breakout
    [usb.sch, usbstub.kicad_pcb, usbstub.sch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]
2020-02-18 un-derped pcb references
    [watch.kicad_pcb, watch.sch]
2020-02-18 re-add 3d files for footprint
    [watch.kicad_pcb]
2020-02-21 checkpoint before retooling board...again.
    [usbstub.kicad_pcb, watch.kicad_pcb, watch.sch]
2020-02-25 finished redesign of main board
    [watch-logic.kicad_pcb, watch-logic.sch, watch-power.kicad_pcb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]
2020-02-25 finish gerbers for three internal boards
    [usbstub-B.Cu.gbr, usbstub-B.Mask.gbr, usbstub-B.Paste.gbr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]
2020-02-25 pcbs ordered :)
    [buttonpanel-B.Cu.gbr, buttonpanel-B.Mask.gbr, buttonpanel-B.Paste.gbr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]
2020-05-02 snapshot for upload to github, now that copyrights are cleared
    [panel.kicad_pcb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]
2020-07-22 add mk2 schematics
    [mk2-B_Cu.gbr, mk2-B_Mask.gbr, mk2-B_Paste.gbr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]
2020-08-21 add rev2mk2
    [flex-B_Cu.gbr, flex-B_Mask.gbr, flex-B_Paste.gbr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]
2020-08-23 commit rev3
    [mk2-B_Cu.gbr, mk2-B_Mask.gbr, mk2-B_Paste.gbr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]
2020-09-02 add rev2 of flex cable
    [flex-B_Cu.gbr, flex-B_Mask.gbr, flex-B_Paste.gbr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]
2021-02-07 schematic checkpoint
    [mk2-B_Cu.gbr, mk2-B_Mask.gbr, mk2-B_Paste.gbr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]
